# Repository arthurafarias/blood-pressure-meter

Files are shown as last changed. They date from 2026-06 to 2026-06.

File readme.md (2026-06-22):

# IoT Measurement Endpoint

A KiCad PCB design for a wireless IoT node that reads analog sensors and drives actuators (DC motor and solenoid valve). Built around the ESP32-C3 module for WiFi/BLE connectivity.

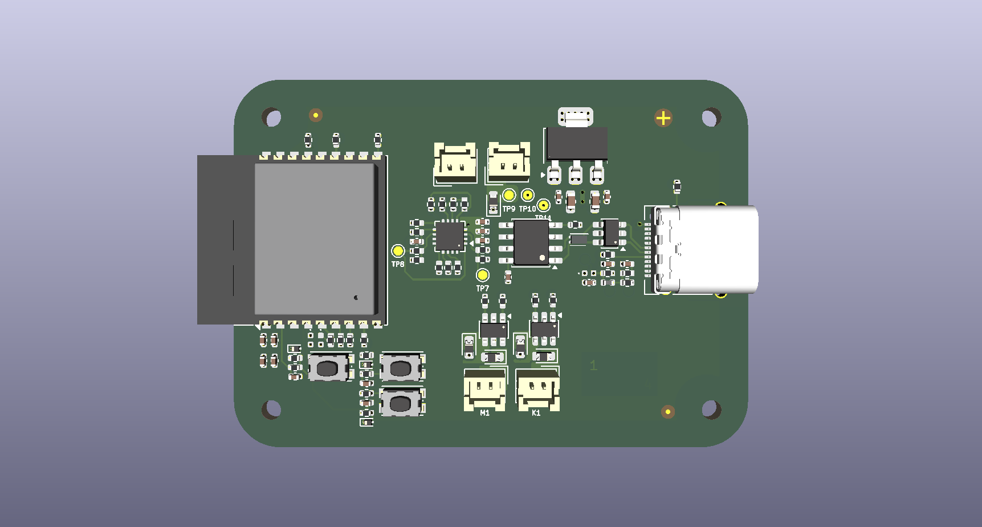
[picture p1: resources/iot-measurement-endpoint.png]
PCB render


## Features

- **ESP32-C3-WROOM-02** — WiFi 4 + Bluetooth LE microcontroller module
- **Analog sensor front-end** — LM324 quad op-amp for signal conditioning
- **Actuator outputs** — DMC2053UVT complementary MOSFET pair for a DC motor and a solenoid valve
- **USB-C** — CH330N USB-to-UART bridge for programming and serial debug; TVS + common-mode choke for ESD/EMI protection
- **Power** — battery connector with 5V USB-C input; NCP1117-3.3 LDO generates the 3.3V rail; polyfuse (0402L050SL) for overcurrent protection
- **User interface** — tactile push buttons (KMR232NG) and status LEDs
- **Fabrication aids** — fiducials, mounting holes, and test points throughout

## Schematic sheets

| Sheet | Contents |
|---|---|
| Top-level | Sheet hierarchy and inter-sheet connections |
| Microcontroller | ESP32-C3-WROOM-02 and decoupling |
| Sensor | LM324 op-amp conditioning circuit |
| Motor | DC motor MOSFET driver with flyback diode |
| Valve | Solenoid valve MOSFET driver |
| 3.3V Regulator | NCP1117-3.3 LDO and bulk capacitors |
| USB Connector | USB-C, CH330N, common-mode choke, TVS array |
| Battery Connector | Battery input and protection diodes |
| Buttons | Tactile switch debounce network |
| LEDs | Status indicators |

## Power architecture

```
USB-C (5V) ──┬── CH330N (serial) ──► UART ──► ESP32-C3
             │
Battery ─────┴── NCP1117-3.3 ──► 3.3V rail ──► ESP32-C3, LM324, logic
                                               └── actuator gate drives

Actuators driven from +6V / +5V rail (motor, valve)
```

## Key components

| Reference | Part | Description |
|---|---|---|
| U (MCU) | ESP32-C3-WROOM-02 | WiFi 4 / BLE 5 module |
| U (USB) | CH330N | USB-to-UART converter, SOIC-8 |
| U (reg) | NCP1117-3.3 | 1A LDO, SOT-223 |
| U (amp) | LM324 | Quad op-amp, DIP-14/SOIC-14 |
| Q | DMC2053UVT | Complementary P+N MOSFET pair, TSOT-23-6 |
| D (ESD) | ESD9B5.0ST5G | TVS diode, signal lines |
| D (USB TVS) | WE-TVS-82400102 | Low-cap TVS array, SOT-23-6 |
| L (USB filter) | 0603USB-142 | Common-mode choke, 98nH, 500mA |
| F | 0402L050SL | Resettable polyfuse |
| SW | KMR232NG ULC LFS | Tactile push button |

## Tools

- **EDA**: KiCad 10.0
- **Simulation**: ngspice (`.cir` files in repo for op-amp circuit verification)
- **3D export**: STEP / STL / GLB (see `iot-measurement-endpoint.step`)

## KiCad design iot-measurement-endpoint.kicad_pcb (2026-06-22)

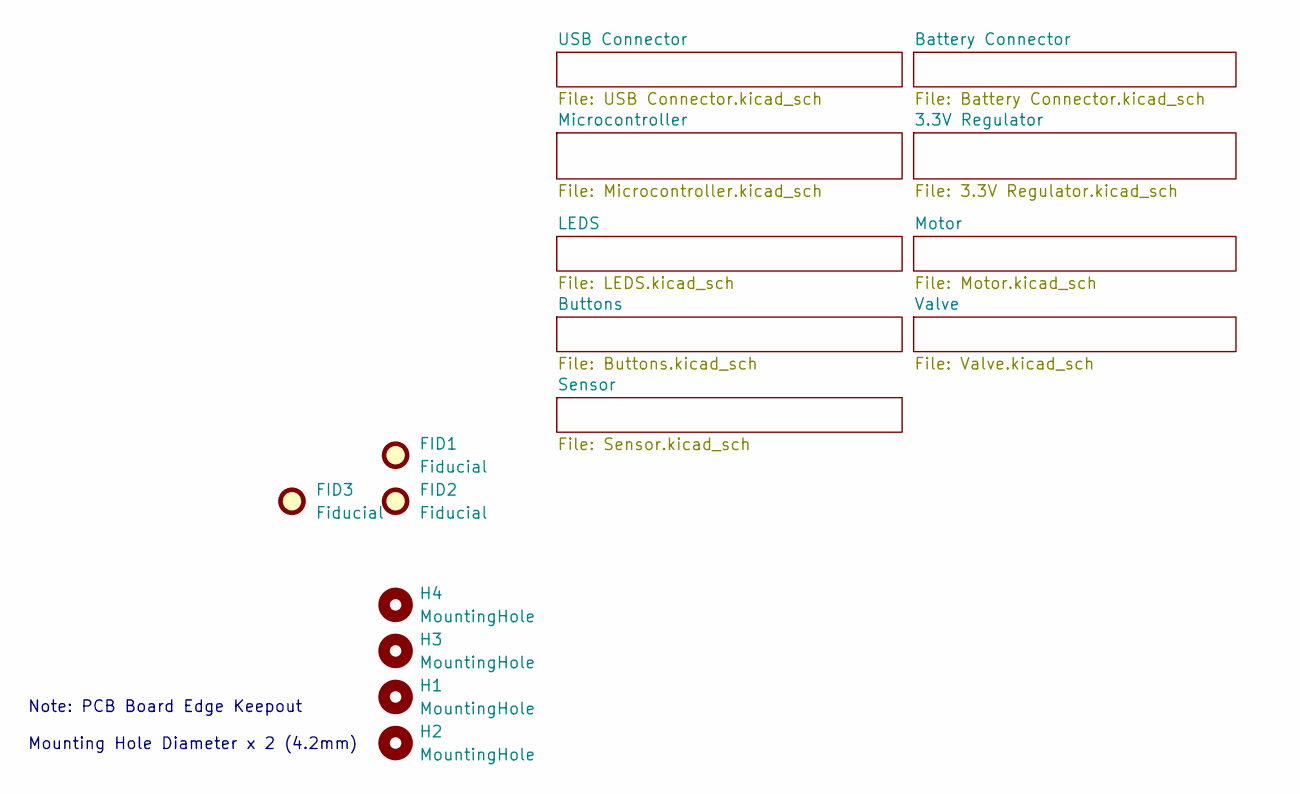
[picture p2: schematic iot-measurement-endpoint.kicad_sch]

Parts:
FID1: Fiducial; Fiducial_Cross_1.5mm_Mask2mm
FID2, FID3: Fiducial; Fiducial_0.5mm_Mask1.5mm
H1, H2, H3, H4: MountingHole; MountingHole_2.1mm

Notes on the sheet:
Note: PCB Board Edge Keepout Mounting Hole Diameter x 2 (4.2mm)

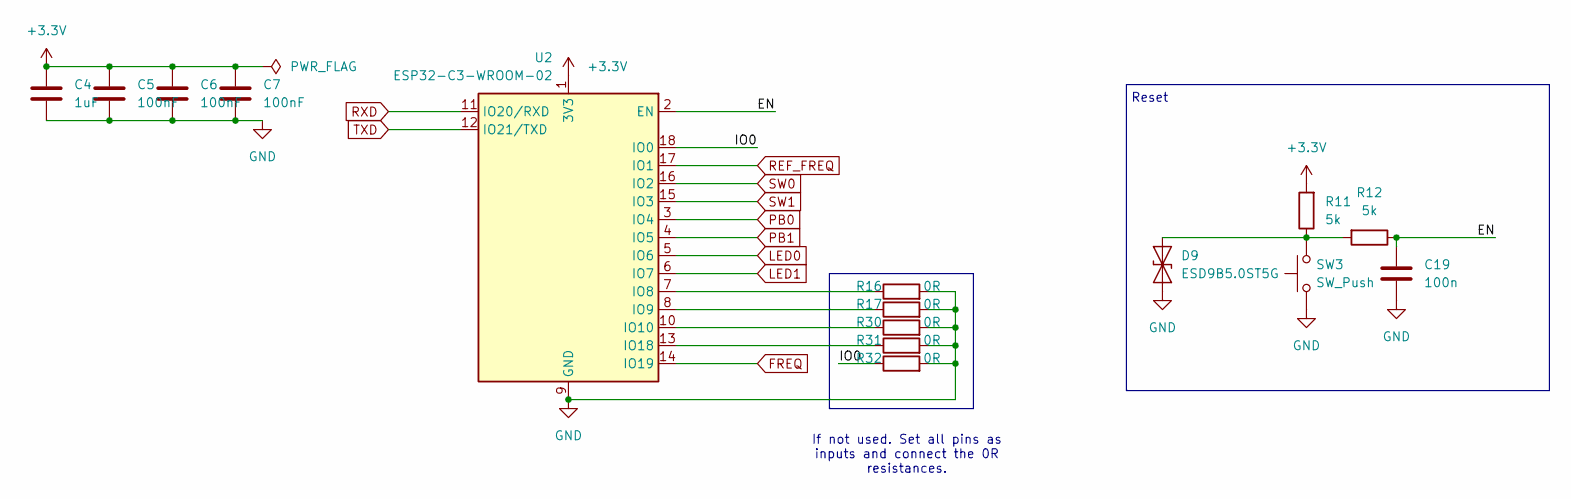
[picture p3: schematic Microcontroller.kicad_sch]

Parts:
C4: 1uF; C_0402_1005Metric
C5, C6, C7: 100nF; C_0402_1005Metric
C19: 100n; C_0402_1005Metric
D9: ESD9B5.0ST5G; D_SOD-923
R11, R12: 5k; R_0402_1005Metric
R16, R17, R30, R31, R32: 0R; R_0402_1005Metric
SW3: SW_Push; SW_Push_1P1T_NO_CK_KMR2
U2: ESP32-C3-WROOM-02

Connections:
+3.3V: C4.1, C5.1, C6.1, C7.1, R11.2, U2.1 (3V3); also elsewhere on the board
/Microcontroller/EN: C19.1, R12.1, U2.2 (EN)
/Microcontroller/IO0: R32.1, U2.18 (IO0)
FREQ: U2.14 (IO19); also elsewhere on the board
GND: C4.2, C5.2, C6.2, C7.2, C19.2, D9.1 (A1), R16.2, R17.2, R30.2, R31.2, R32.2, SW3.1, U2.9 (GND), U2.19 (GND); also elsewhere on the board
LED0: U2.5 (IO6); also elsewhere on the board
LED1: U2.6 (IO7); also elsewhere on the board
unnamed: D9.2 (A2), R11.1, R12.2, SW3.2
unnamed: R16.1, U2.7 (IO8)
unnamed: R17.1, U2.8 (IO9)
unnamed: R30.1, U2.10 (IO10)
unnamed: R31.1, U2.13 (IO18)
PB0: U2.3 (IO4); also elsewhere on the board
PB1: U2.4 (IO5); also elsewhere on the board
REF_FREQ: U2.17 (IO1); also elsewhere on the board
RXD: U2.11 (IO20/RXD); also elsewhere on the board
SW0: U2.16 (IO2); also elsewhere on the board
SW1: U2.15 (IO3); also elsewhere on the board
TXD: U2.12 (IO21/TXD); also elsewhere on the board

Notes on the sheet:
Reset
If not used. Set all pins as inputs and connect the 0R resistances.

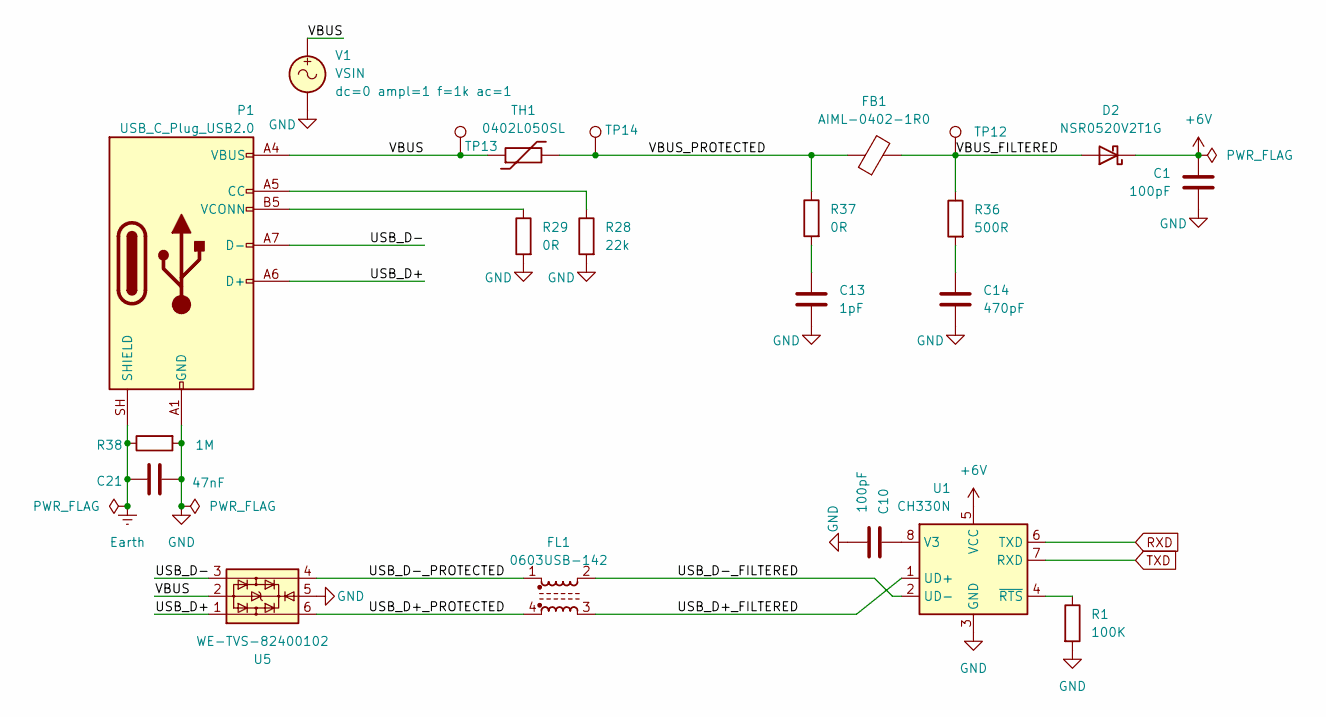
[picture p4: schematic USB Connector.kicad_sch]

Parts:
C1, C10: 100pF; C_0402_1005Metric
C13: 1pF; C_0402_1005Metric
C14: 470pF; C_0402_1005Metric
C21: 47nF; C_0402_1005Metric
D2: NSR0520V2T1G; D_0402_1005Metric
FB1: AIML-0402-1R0; L_0402_1005Metric
FL1: 0603USB-142; L_CommonModeChoke_Coilcraft_0603USB
P1: USB_C_Plug_USB2.0; USB_C_Receptacle_Amphenol_12401548E4-2A_CircularHoles
R1: 100K; R_0402_1005Metric
R28: 22k; R_0402_1005Metric
R29, R37: 0R; R_0402_1005Metric
R36: 500R; R_0402_1005Metric
R38: 1M; R_0402_1005Metric
TH1: 0402L050SL; R_0402_1005Metric
TP12, TP13, TP14: TestPoint; TestPoint_Pad_D1.0mm
U1: CH330N; SOIC-8_3.9x4.9mm_P1.27mm
U5: WE-TVS-82400102; SOT-23-6
V1: VSIN

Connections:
+6V: C1.1, D2.1 (K), U1.5 (VCC); also elsewhere on the board
/USB Connector/USB_D+: P1.A6 (D+), U5.1
/USB Connector/USB_D+_FILTERED: FL1.3, U1.1 (UD+)
/USB Connector/USB_D+_PROTECTED: FL1.4, U5.6
/USB Connector/USB_D-: P1.A7 (D-), U5.3
/USB Connector/USB_D-_FILTERED: FL1.2, U1.2 (UD-)
/USB Connector/USB_D-_PROTECTED: FL1.1, U5.4
/USB Connector/VBUS: P1.A4 (VBUS), P1.A9 (VBUS), P1.B4 (VBUS), P1.B9 (VBUS), TH1.1, TP13.1 (1_1), U5.2, V1.1
/USB Connector/VBUS_FILTERED: D2.2 (A), FB1.2, R36.1, TP12.1 (1_1)
/USB Connector/VBUS_PROTECTED: FB1.1, R37.1, TH1.2, TP14.1 (1_1)
Earth: C21.1, P1.SH (SHIELD), R38.1
GND: C1.2, C10.2, C13.2, C14.2, C21.2, P1.A1 (GND), P1.A12 (GND), P1.B1 (GND), P1.B12 (GND), R1.2, R28.2, R29.2, R38.2, U1.3 (GND), U5.5, V1.2; also elsewhere on the board
unnamed: C13.1, R37.2
unnamed: C14.1, R36.2
unnamed: P1.A5 (CC), R28.1
unnamed: P1.B5 (VCONN), R29.1
unnamed: C10.1, U1.8 (V3)
unnamed: R1.1, U1.4 (~RTS)
RXD: U1.6 (TXD); also elsewhere on the board
TXD: U1.7 (RXD); also elsewhere on the board

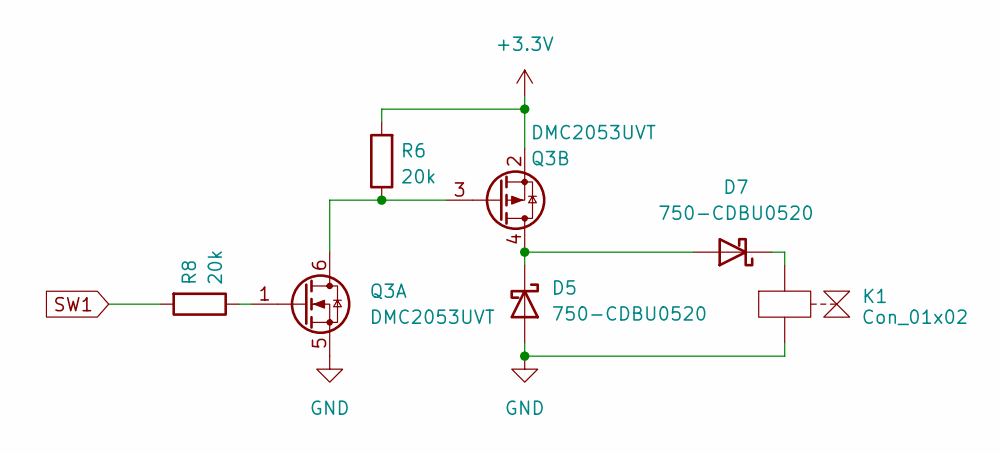
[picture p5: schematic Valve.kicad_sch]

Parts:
D5, D7: 750-CDBU0520; D_0603_1608Metric
K1: Con_01x02; Hirose_DF13-02P-1.25DSA_1x02_P1.25mm_Vertical
Q3: DMC2053UVT; TSOT-23-6
R6, R8: 20k; R_0402_1005Metric

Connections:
+3.3V: Q3.2 (S), R6.2; also elsewhere on the board
GND: D5.2 (A), K1.2 (A), Q3.5 (S); also elsewhere on the board
unnamed: D5.1 (K), D7.2 (A), Q3.4 (D)
unnamed: D7.1 (K), K1.1 (K)
unnamed: Q3.3 (G), Q3.6 (D), R6.1
unnamed: Q3.1 (G), R8.1
SW1: R8.2; also elsewhere on the board

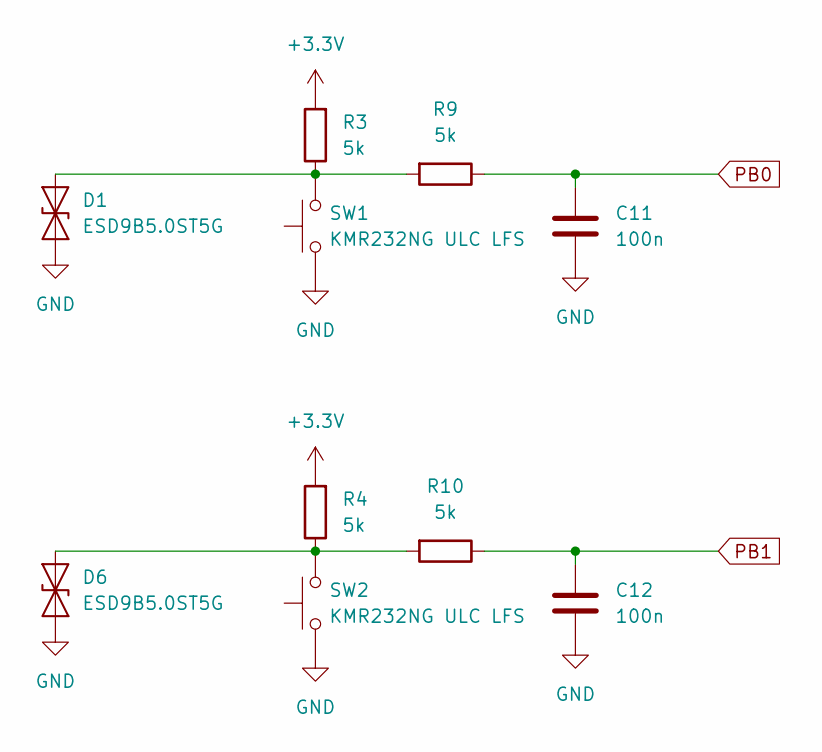
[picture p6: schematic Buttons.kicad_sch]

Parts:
C11, C12: 100n; C_0402_1005Metric
D1, D6: ESD9B5.0ST5G; D_SOD-923
R3, R4, R9, R10: 5k; R_0402_1005Metric
SW1, SW2: KMR232NG ULC LFS; SW_Push_1P1T_NO_CK_KMR2

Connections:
+3.3V: R3.2, R4.2; also elsewhere on the board
GND: C11.2, C12.2, D1.1 (A1), D6.1 (A1), SW1.1, SW2.1; also elsewhere on the board
unnamed: D1.2 (A2), R3.1, R9.2, SW1.2
unnamed: D6.2 (A2), R4.1, R10.2, SW2.2
PB0: C11.1, R9.1; also elsewhere on the board
PB1: C12.1, R10.1; also elsewhere on the board

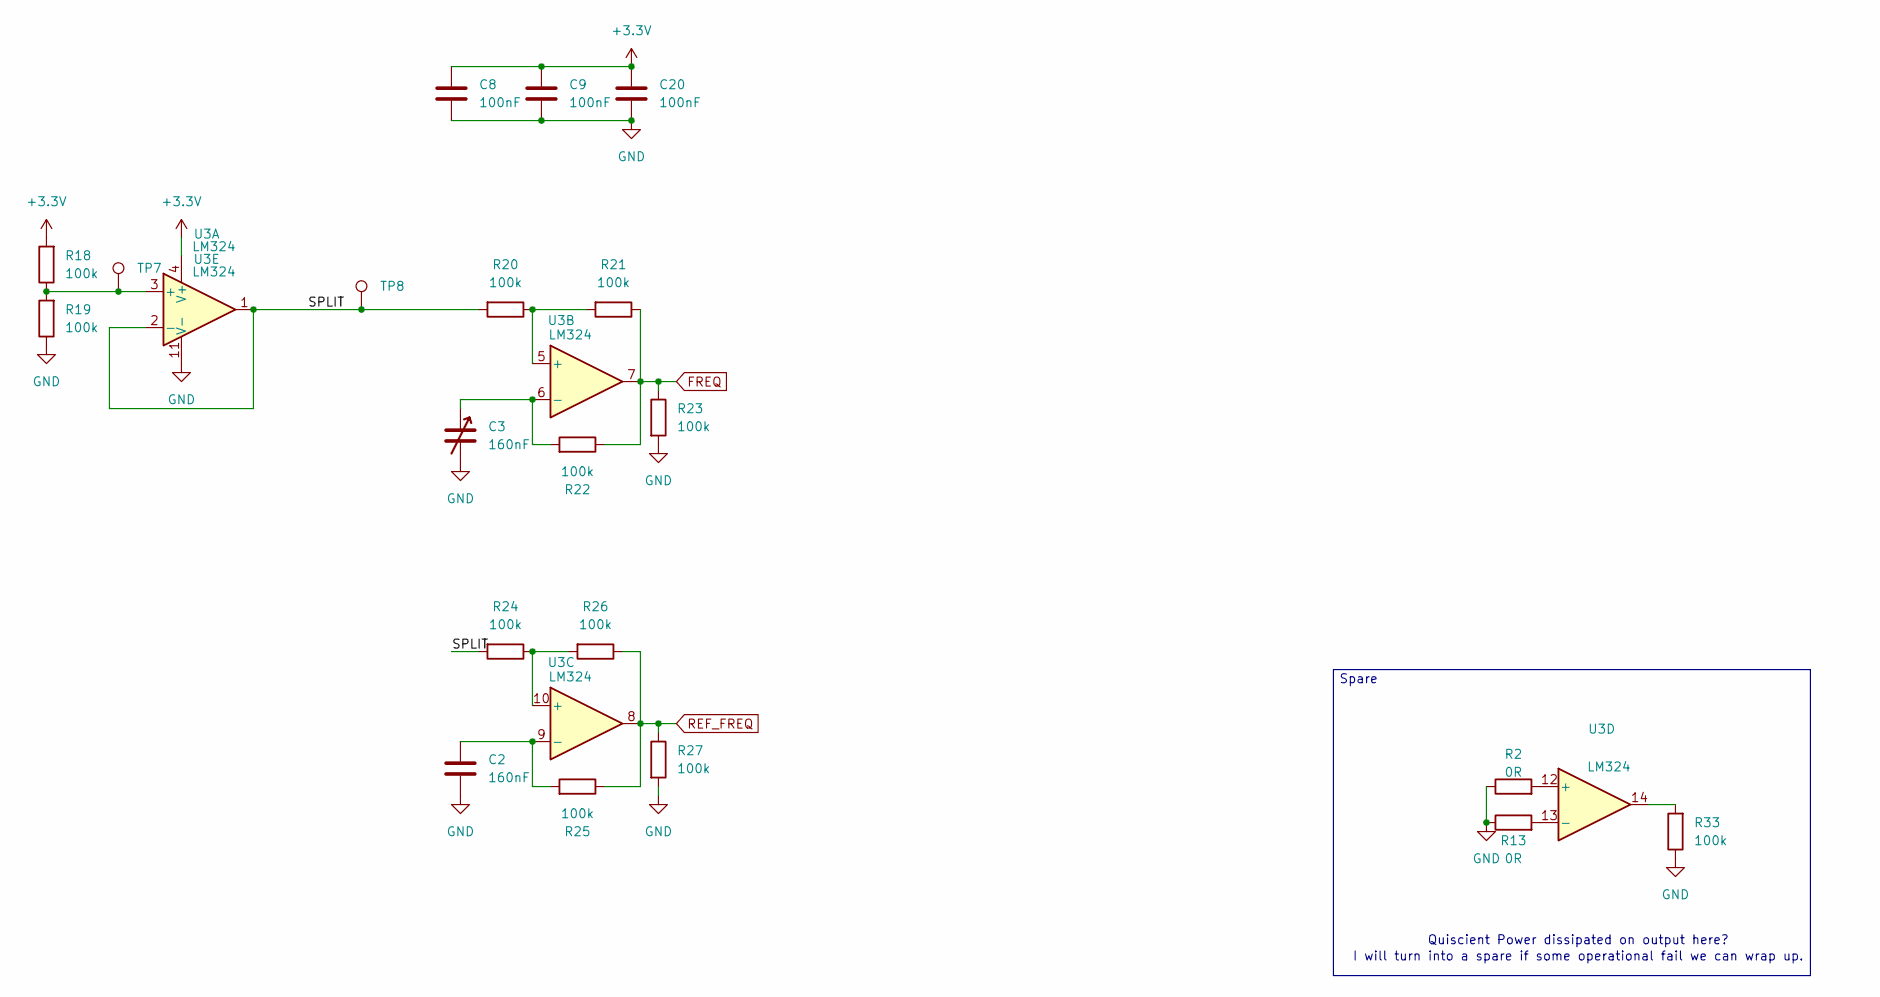
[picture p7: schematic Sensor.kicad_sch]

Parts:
C2: 160nF; C_0402_1005Metric
C3: 160nF; Hirose_DF13-02P-1.25DSA_1x02_P1.25mm_Vertical
C8, C9, C20: 100nF; C_0402_1005Metric
R2, R13: 0R; R_0402_1005Metric
R18, R19, R20, R21, R22, R23, R24, R25, R26, R27, R33: 100k; R_0402_1005Metric
TP7, TP8: TestPoint; TestPoint_Pad_D1.0mm
U3: LM324; WQFN-16-1EP_3x3mm_P0.5mm_EP1.68x1.68mm

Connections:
+3.3V: C8.1, C9.1, C20.1, R18.2, U3.4 (V+); also elsewhere on the board
/Sensor/SPLIT: R20.2, R24.2, TP8.1 (1_1), U3.1, U3.2 (-)
FREQ: R21.1, R22.1, R23.1, U3.7; also elsewhere on the board
GND: C2.2, C3.2, C8.2, C9.2, C20.2, R2.1, R13.1, R19.1, R23.2, R27.2, R33.1, U3.11 (V-); also elsewhere on the board
unnamed: R33.2, U3.14
unnamed: R18.1, R19.2, TP7.1 (1_1), U3.3 (+)
unnamed: R20.1, R21.2, U3.5 (+)
unnamed: C3.1, R22.2, U3.6 (-)
unnamed: R24.1, R26.2, U3.10 (+)
unnamed: C2.1, R25.2, U3.9 (-)
unnamed: R2.2, U3.12 (+)
unnamed: R13.2, U3.13 (-)
REF_FREQ: R25.1, R26.1, R27.1, U3.8; also elsewhere on the board

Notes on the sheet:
Quiscient Power dissipated on output here?
I will turn into a spare if some operational fail we can wrap up.
Spare

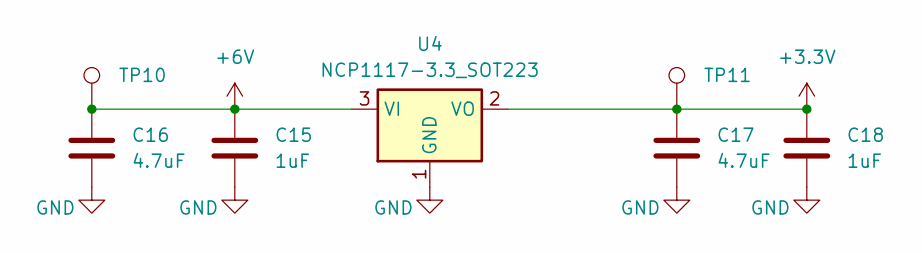
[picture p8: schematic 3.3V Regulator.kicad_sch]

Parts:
C15, C18: 1uF; C_0402_1005Metric
C16, C17: 4.7uF; C_0603_1608Metric
TP10, TP11: TestPoint; TestPoint_Pad_D1.0mm
U4: NCP1117-3.3_SOT223; SOT-223-3_TabPin2

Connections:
+3.3V: C17.1, C18.1, TP11.1 (1_1), U4.2 (VO); also elsewhere on the board
+6V: C15.1, C16.1, TP10.1 (1_1), U4.3 (VI); also elsewhere on the board
GND: C15.2, C16.2, C17.2, C18.2, U4.1 (GND); also elsewhere on the board

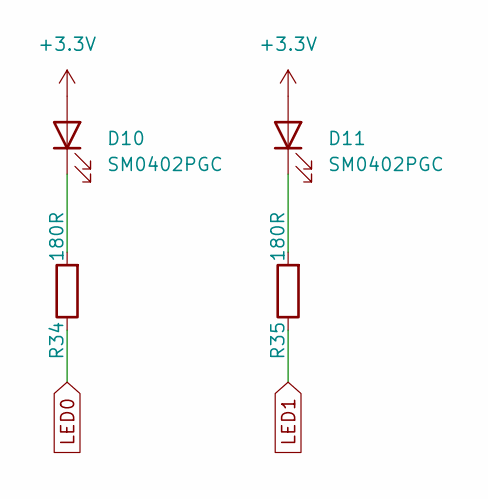
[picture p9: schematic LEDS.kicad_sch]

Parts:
D10, D11: SM0402PGC; D_0402_1005Metric
R34, R35: 180R; R_0402_1005Metric

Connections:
+3.3V: D10.2 (A), D11.2 (A); also elsewhere on the board
LED0: R34.1; also elsewhere on the board
LED1: R35.1; also elsewhere on the board
unnamed: D10.1 (K), R34.2
unnamed: D11.1 (K), R35.2

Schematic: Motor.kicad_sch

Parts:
D4, D8: 750-CDBU0520; D_0603_1608Metric
M1: Motor_DC; Hirose_DF13-02P-1.25DSA_1x02_P1.25mm_Vertical
Q2: DMC2053UVT; TSOT-23-6
R5, R7: 20k; R_0402_1005Metric

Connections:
+6V: Q2.2 (S), R5.2; also elsewhere on the board
GND: D4.2 (A), M1.2 (-), Q2.5 (S); also elsewhere on the board
unnamed: D4.1 (K), D8.2 (A), Q2.4 (D)
unnamed: D8.1 (K), M1.1 (+)
unnamed: Q2.3 (G), Q2.6 (D), R5.1
unnamed: Q2.1 (G), R7.1
SW0: R7.2; also elsewhere on the board

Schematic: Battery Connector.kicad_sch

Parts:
BT1: Battery; Hirose_DF13-02P-1.25DSA_1x02_P1.25mm_Vertical
D3: 750-CDBU0520; D_0603_1608Metric
TP9: TestPoint; TestPoint_Pad_D1.0mm

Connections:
+6V: D3.1 (K); also elsewhere on the board
GND: BT1.2 (-); also elsewhere on the board
unnamed: BT1.1 (+), D3.2 (A), TP9.1 (1_1)

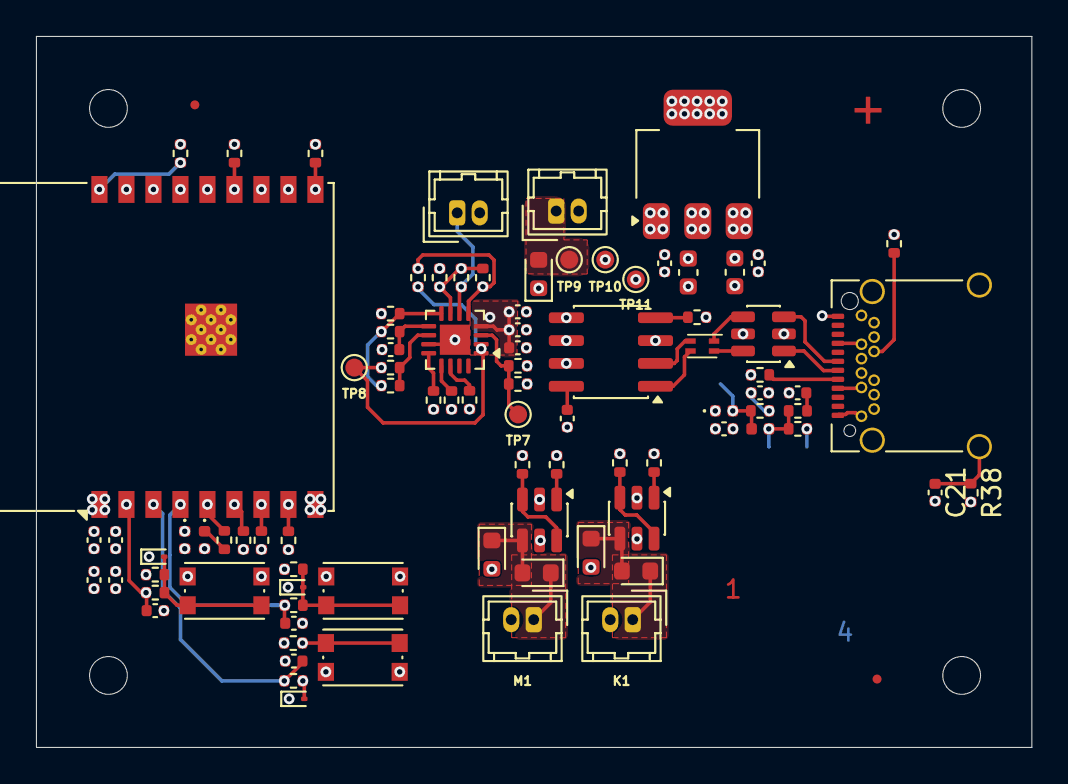
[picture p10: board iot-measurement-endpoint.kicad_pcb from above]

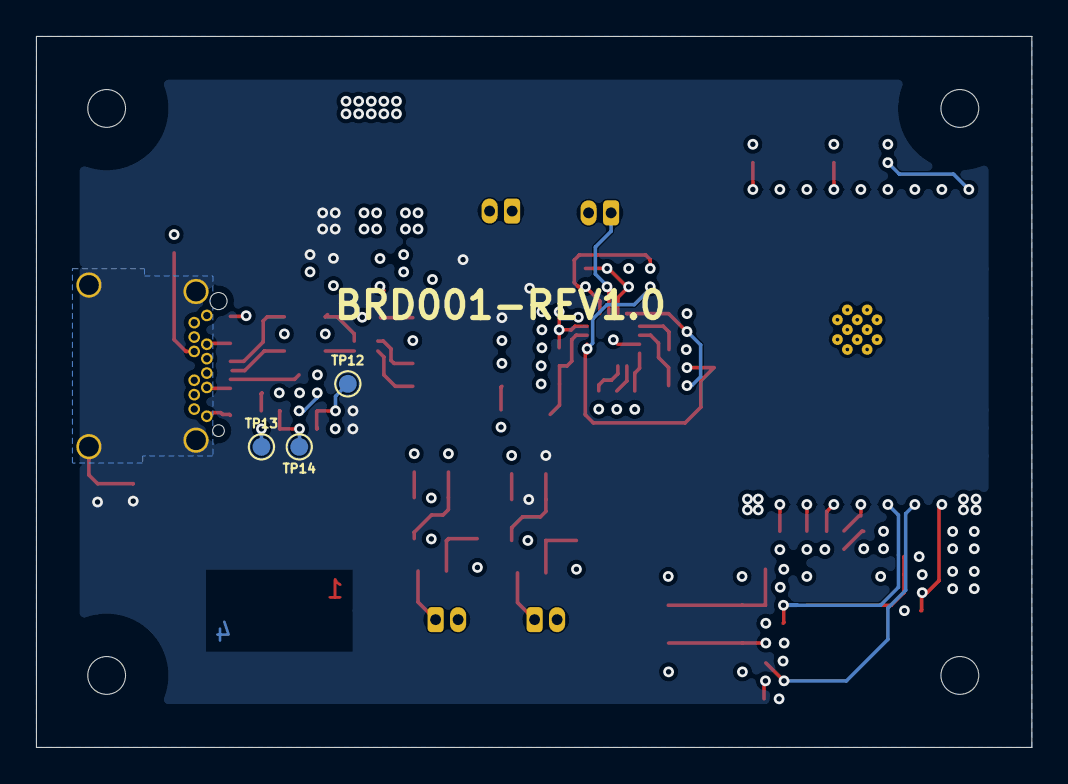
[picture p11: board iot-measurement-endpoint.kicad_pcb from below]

Board: 4 copper layers, 55.3 x 39.5 mm, 100 parts (3 on the bottom side), 58 nets.

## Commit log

2026-06-22 Fixing power planes for motor and valve outputs
    [iot-measurement-endpoint.kicad_pcb]
2026-06-22 Fixing filter response to put loads at 10 MHz signals and 1 GHz signals (low pass RC and ferrite) at DC power supply (rejecting high frequency noise in the power supply).
    [USB Connector.kicad_sch, iot-measurement-endpoint.kicad_pcb]
2026-06-22 Routing improvement
    [3.3V Regulator.kicad_sch, Microcontroller.kicad_sch, USB Connector.kicad_sch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]
2026-06-22 Unifying 3.3V plane with the regulator output (removing net tie)
    [3.3V Regulator.kicad_sch, iot-measurement-endpoint.kicad_pcb]
2026-06-22 Reducing VBUS area to remove 3.3V plane discontinuity
    [iot-measurement-endpoint.kicad_pcb]
2026-06-22 Adding resistance and capacitance connecting GND and Earth in the peripheral device
    [USB Connector.kicad_sch, iot-measurement-endpoint.kicad_pcb]
